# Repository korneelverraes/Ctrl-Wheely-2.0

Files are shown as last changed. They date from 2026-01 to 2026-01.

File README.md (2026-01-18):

# Ctrl-Wheely
*An innovative interface that elevates safety in modern vehicles to a higher level.* 

*Projectteam: Korneel Verraes; Warre Robbe; Seppe Nijs; Bram Tops*

19/01/2026

## Introduction
In contemporary cars, large touchscreens force drivers to take their eyes off the road, even for simple actions. This conflicts with the need for focus and safety while driving. Ctrl-Wheely originates from this tension and rethinks vehicle control more naturally. The system combines a modular rotary controller with targeted haptic feedback, allowing functions to feel intuitive and to be operated by touch rather than sight.

Essential information such as climate and media settings is displayed on a head-up display directly within the driver’s field of view. Through a carefully considered mechanical design, Ctrl-Wheely creates a robust physical interaction that feels faster, causes less distraction, and restores balance to the driving experience.

<div style="display:flex; gap:20px;">
  Wide angle view
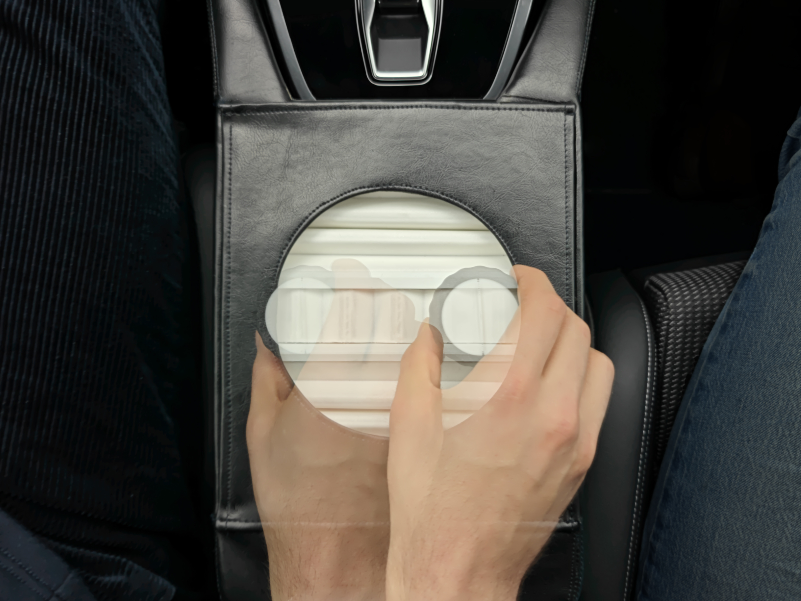
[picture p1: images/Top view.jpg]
Top view
  
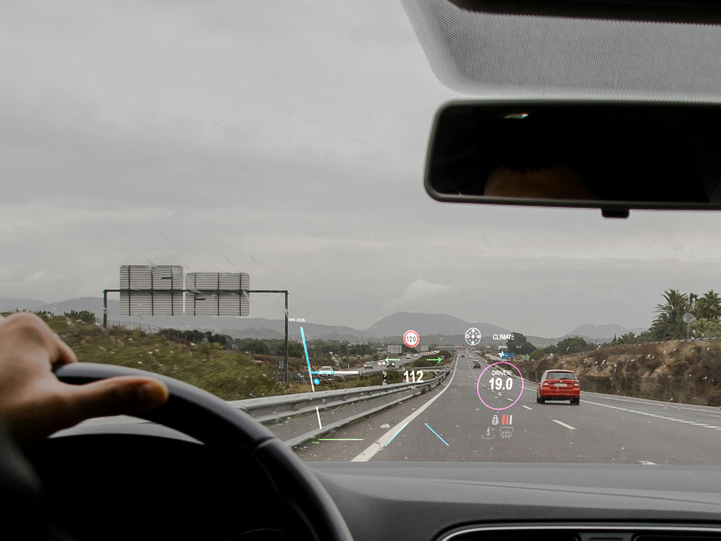
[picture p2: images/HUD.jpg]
HUD
  
</div>

## Embodiment

The product architecture consists of two main assemblies. All design files are located in the `CAD-Files` folder. Use `ASSY_V6.prt` or `ASSY_V6.stp` for the full assembly of the entire system, while `ASSY V5.prt` contains the standalone dial assembly.

**The dial** serves as a smart rotary knob inspired by [Scott Bezz's SmartKnob project](https://github.com/scottbez1/smartknob). Its primary functions include rotation with programmable haptic feedback, a central short or long press, and dedicated left and right clicking actions. The design is focused on ergonomic and intuitive use.

**The gantry system** is inspired by 3D printer mechanics and utilizes a central hub on which the dial is mounted, supported by two axes. This allows the controller to move physically within the console to navigate different menus or settings. To protect the internal mechanism from dust or debris, a dual cover system has been implemented. These covers must be printed in TPU (the softer the better for flexibility), while all other structural parts can be printed in PETG or ASA for better heat resistance in automotive environments.

<div style="display:flex; gap:20px;">
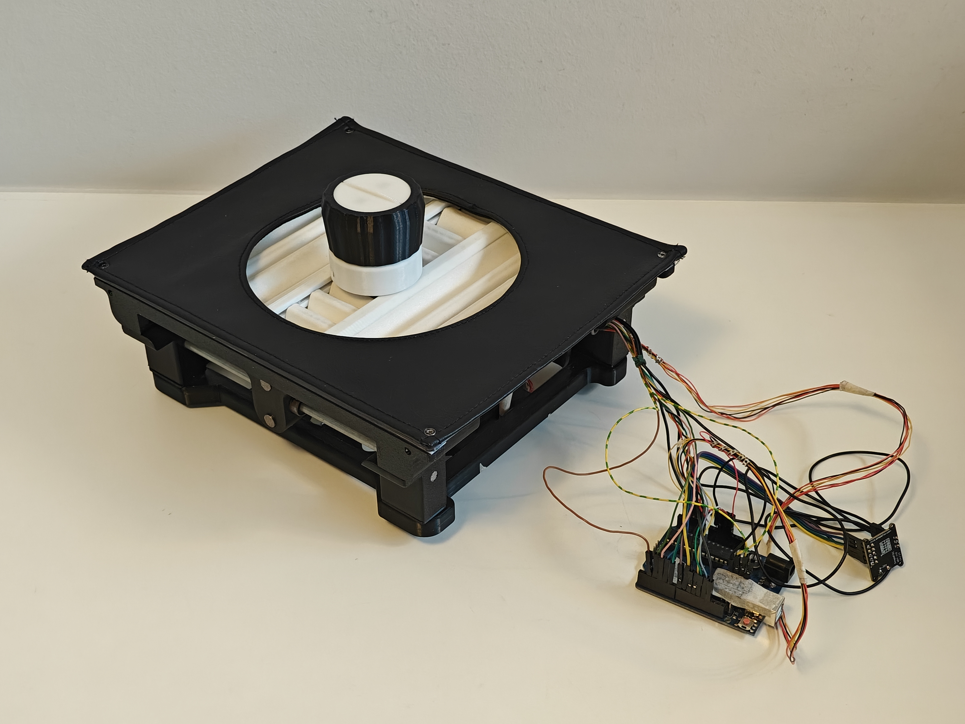
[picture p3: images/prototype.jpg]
Prototype
  
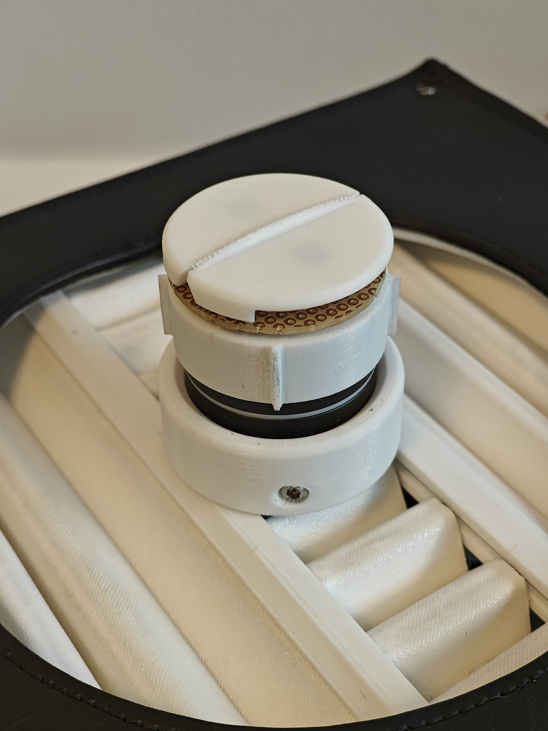
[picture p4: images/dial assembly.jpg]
Dial assembly
  
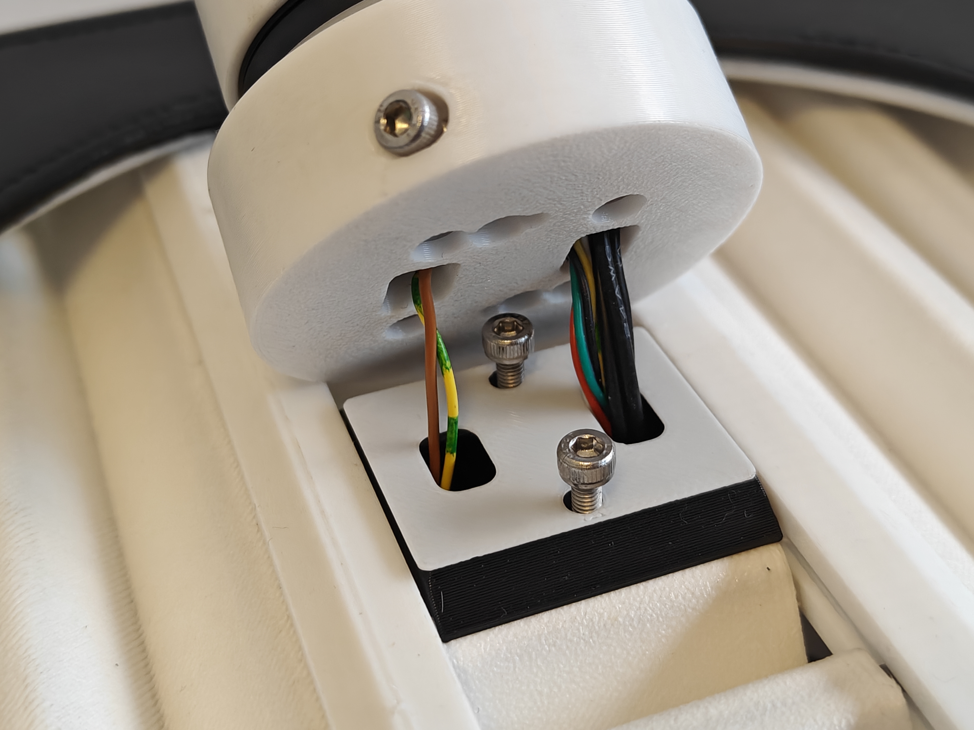
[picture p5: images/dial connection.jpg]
Dial connection
  
</div>

### Bill of Materials (BOM)
#### Mechanical components:
- 2 x Smooth steel rod (Ø6 x 217.5mm)
- 2 x Smooth steel rod (Ø8 x 190mm)
- 2 x LM8UU linear ball bearing
- 2 x LM6UU linear ball bearing
- 5 x Connecting screws & sleeves (for snapping positions)
- 1 x Neodymium magnet (Ø6 x 16mm)
- 6 x Threaded rod (Ø3 x 205mm)
- 4 x Threaded rod (Ø1 x 205mm)

#### Fasteners (dial):
- 2 x M3 x 8
- 4 x M2.5 x 16
- 4 x M2.5 x 6
- 4 x M2.5 x 10 (included in the motor kit)

#### Fasteners (gantry):
- 4 x M3 x 16
- 2 x M3 x 8
- 4 x M3 x 10
- 4 x M2 x 6

The prototype has been specifically engineered to fit the interior geometry of an **Audi Q4 e-tron**.

## Hardware

The system uses an Arduino Uno to bridge the gap between physical movement and digital feedback. All components are wired according to the electrical scheme and physical setup shown below.

### Components

- 1 x Arduino Uno  
- 1 x iPower GM3506 Gimbal Motor with Encoder  
- 1 x SimpleFOC Mini motor driver  
- 5 x DRV5053 Analog-Bipolar Hall Effect Sensors  
- 2 x Small push button (6 mm)  
- 1 x Large push button (12 mm)  
- 1 x DC power supply (8-30 V)  
- 1 x Circular prototyping board (diameter 43 mm)  

### Electrical Diagram and Hardware Setup

<div style="display:flex; gap:20px;">
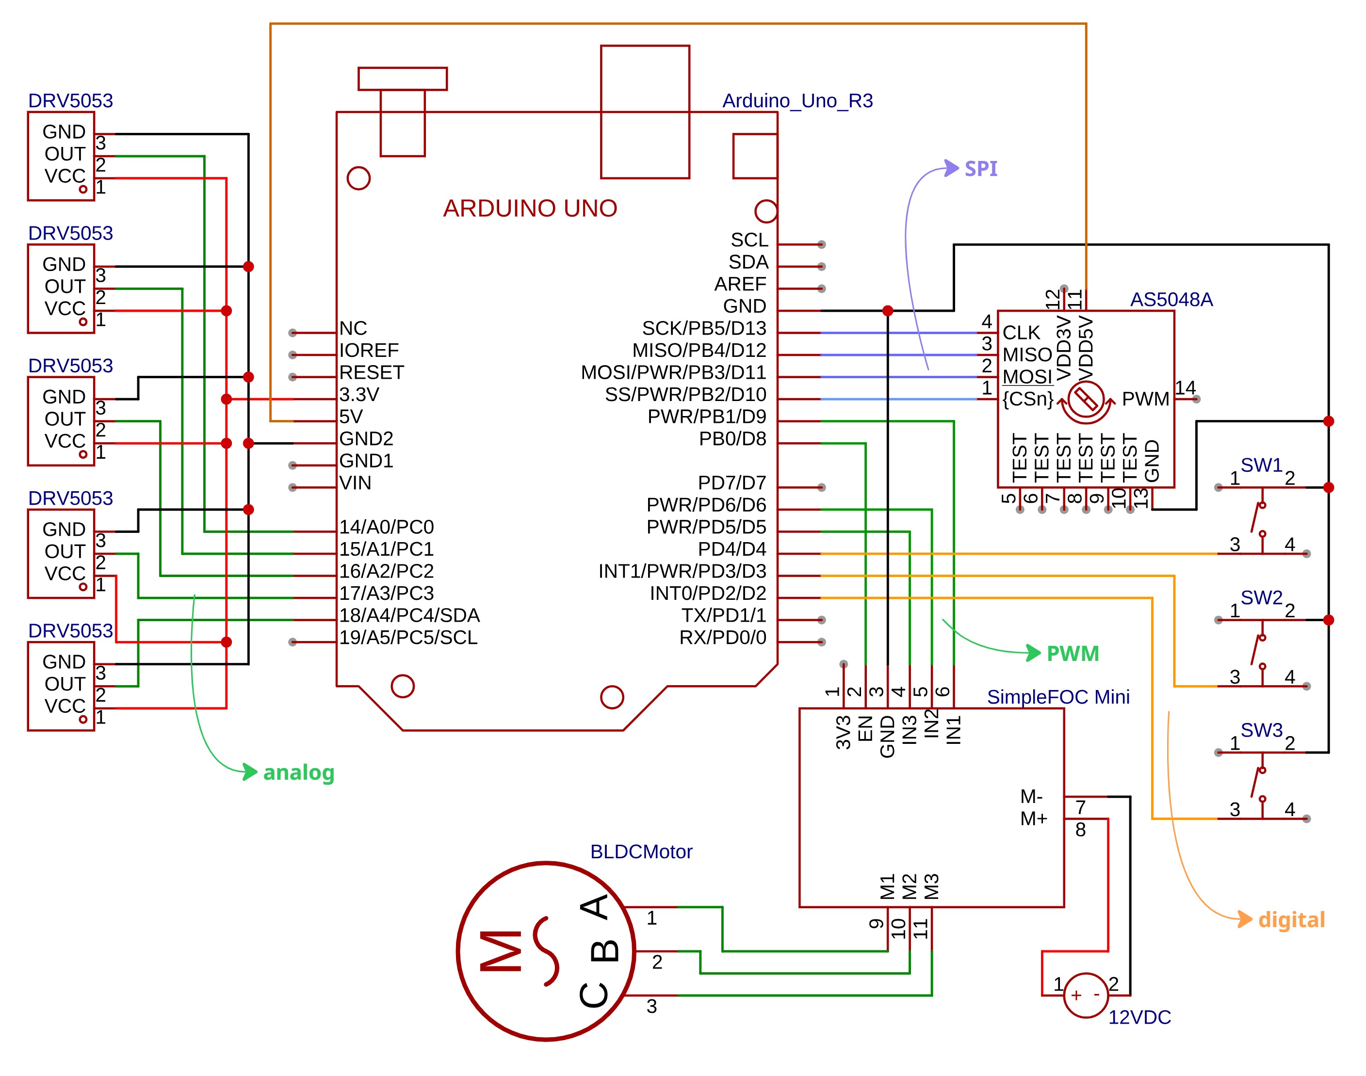
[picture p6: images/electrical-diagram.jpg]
Electrical Diagram
  
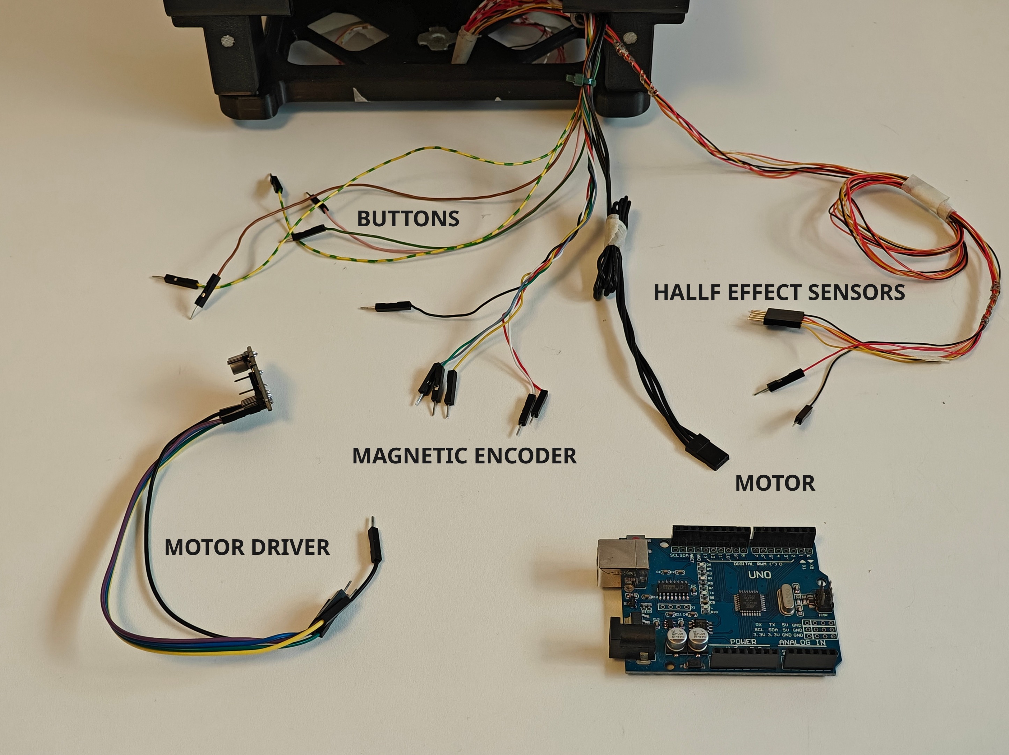
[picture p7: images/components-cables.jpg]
Hardware Setup Photo
  
</div>

| **Component** | **Connection** |
|---|---|
| **Motor driver** | **Arduino UNO** |
| EN (purple) | D8 |
| IN3 (blue) | D5 |
| IN2 (green) | D6 |
| IN1 (yellow) | D9 |
| GND (black) | GND |
| | |
| **Magnetic encoder** | **Arduino UNO** |
| GND (white) | GND |
| VDD (red) | +5V |
| MISO (green) | D12 |
| MOSI (yellow) | D11 |
| SCL (purple) | D13 |
| CS (black) | D10 |
| | |
| **Hall effect sensors** | **Arduino UNO** |
| VCC | +3.3V |
| GND | GND |
| OUT x 5 | A0 - A4 |
| | |
| **Push button (press)** | **Arduino UNO** |
| OUT (brown) | D2 |
| GND (yellow-green) | GND |
| | |
| **Push button (left / right)** | **Arduino UNO** |
| OUT left (green) | D3 |
| OUT right (pink) | D4 |
| GND (yellow-green) | GND |
| | |
| **Motor phase cables** | **Motor driver** |
| A (black) | M1 |
| B (black) | M2 |
| C (black) | M3 |

## Software
### Arduino

The Arduino serves as the core controller, managing all hardware interactions and real-time feedback loops. The complete implementation, found in `Ctrl-Wheely.ino`, leverages the [SimpleFOC library](https://simplefoc.com/) to drive the gimbal motor. This allows for high-precision haptic feedback that changes dynamically based on the active function and user input.

Before running the main Arduino code, the correct physical positions of the hall effect sensors must be determined. This is done using the calibration sketch `Magnet_pos_test.ino`. This sketch allows you to read and verify the sensor outputs while moving the magnet position.

The motor driver voltage must be set according to the external power supply used in the setup. Make sure to update the voltage value in the Arduino code to match your power supply.

```cpp
driver.voltage_power_supply = 11,2;
```

### PyGame
The project includes a Head-Up Display (HUD) that projects information onto the windshield, indicating which function is currently being controlled via the dial. In a previous iteration of the project, the HUD was developed using ProtoPie and connected to an Arduino. Due to the limitations of ProtoPie, all scenes are now fully implemented in Python using the PyGame library.

The user interface that was designed and tested within the course User-Centered Design has been recreated almost one-to-one in PyGame. This approach ensures that the validated and positively received UX is preserved in the final implementation. The system is not a simulated “Wizard of Oz” interface, but a fully functional and directly responsive HUD that accurately reflects the user’s interactions with the dial.

Within PyGame, it is possible to receive serial data directly from the Arduino, to which the dial is connected. This incoming serial input is used to dynamically update elements of the HUD in real time. The PyGame implementation was further extended with additional functionalities, including: Extra buttons, Submenus, Variable values per passenger or driver and Additional configurable interface elements

The full PyGame implementation of the HUD can be found in `UI_HUD_pygame.py`. 

Make sure to set the correct COM port on **line 55**.

```py
ser = serial.Serial('COM5', 115200, timeout=0)
```

For HUD usage, uncomment **lines 1027 and 1028** to mirror the screen over the x-axis. In this project Superdesk was used to project the HUD on a phone or tablet for projecting the HUD in the window of a car.

```py
#canvas = pygame.transform.flip(screen, False, True)
#screen.blit(canvas, (0,0))
```

<div style="display:flex; gap:20px;">
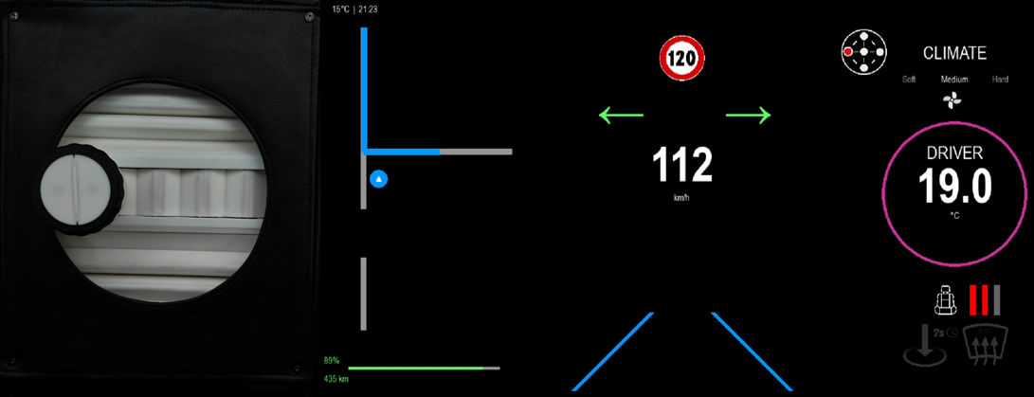
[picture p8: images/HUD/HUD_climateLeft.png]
Climate Left
  
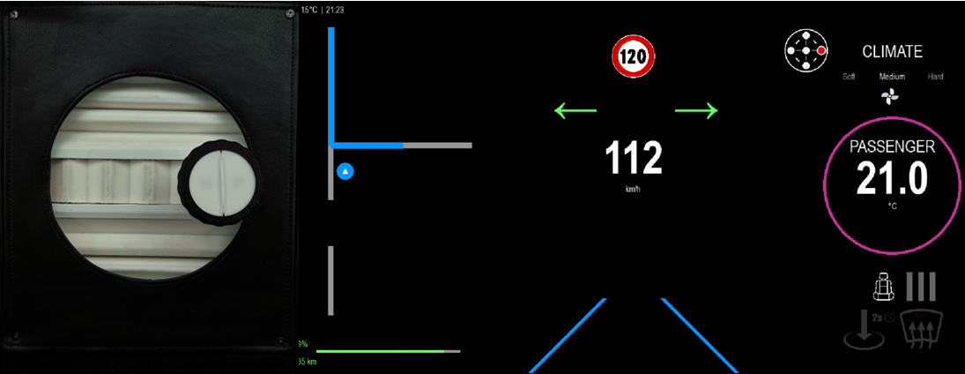
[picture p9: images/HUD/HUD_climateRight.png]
climate Right
  
</div>

<div style="display:flex; gap:20px;">
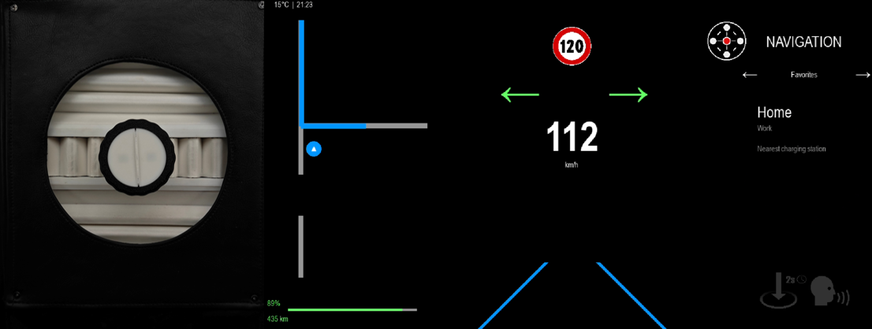
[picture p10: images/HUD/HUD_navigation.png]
  
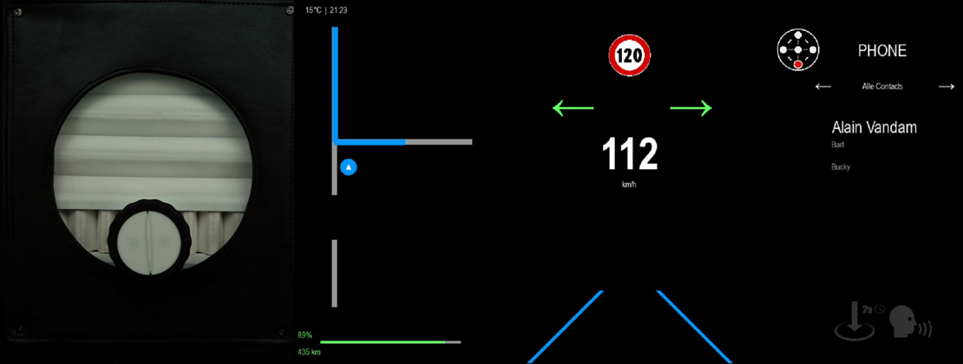
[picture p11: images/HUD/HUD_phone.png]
  
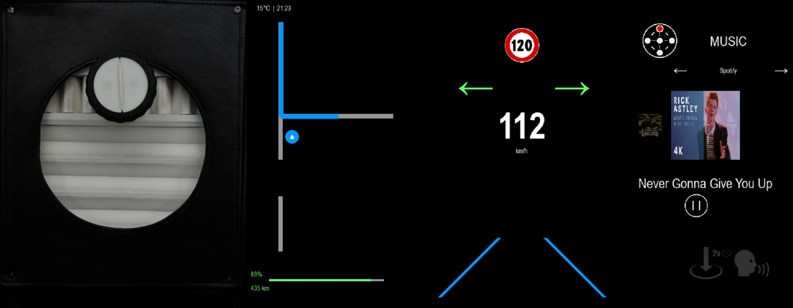
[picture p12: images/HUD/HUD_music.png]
  
</div>

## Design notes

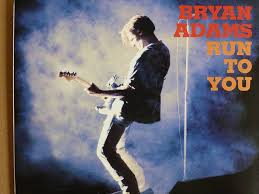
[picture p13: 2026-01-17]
software/album_d.jpg

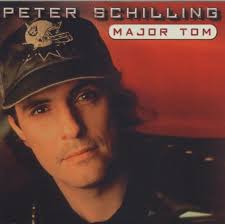
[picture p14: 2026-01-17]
software/album_e.jpg

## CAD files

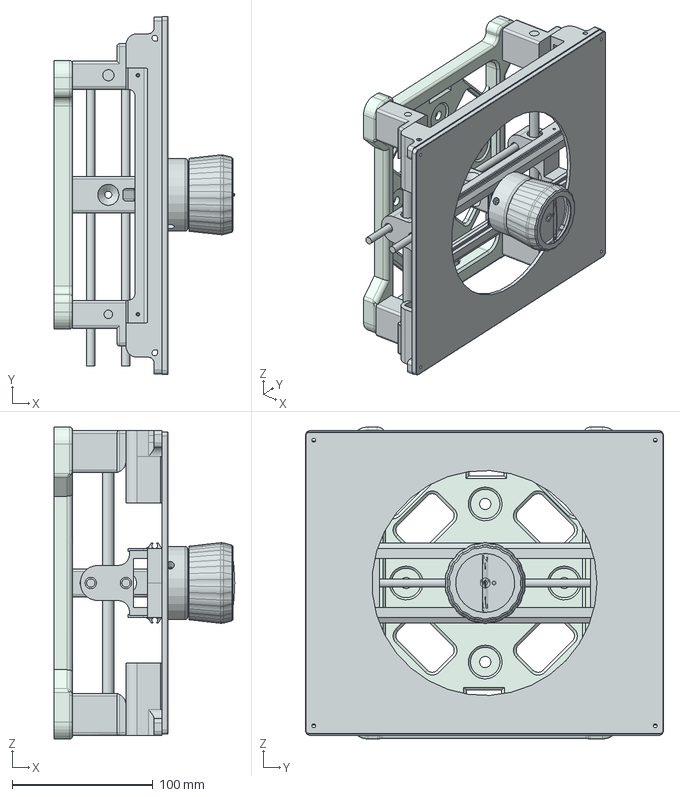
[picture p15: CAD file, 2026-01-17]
CAD files/ASSY_V6.stp
128.4 x 254.8 x 221.8 mm
rod short V5 x 2
MID rail V5 x 2
MID cross block V5 x 2
outer rail V5 x 2
rod long V5 x 2
corner piece V5 x 3
knob V5
buttonplate V5
knob spacer V5
base plate V5
clips V5
button PCB V5
button base V5
ring V5
top plate V5
MID central block V5
MID central block cover V5
bottom plate V5

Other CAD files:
CAD files/ASSY V5.prt
CAD files/ASSY_V6.prt
CAD files/MID central block V5.prt
CAD files/MID central block cover V5.prt
CAD files/MID cross block V5.prt
CAD files/MID rail V5.prt
CAD files/base plate V5.prt
CAD files/bottom plate V5.prt
CAD files/button PCB V5.prt
CAD files/button base V5.prt
CAD files/buttonplate V5.prt
CAD files/clips V5.prt
CAD files/corner piece V5.prt
CAD files/knob V5.prt
CAD files/knob spacer V5.prt
CAD files/outer rail V5.prt
CAD files/ring V5.prt
CAD files/rod long V5.prt
CAD files/rod short V5.prt
CAD files/top plate V5.prt
CAD files/tpu cover v2.prt
CAD files/tpu coverbig v2.prt

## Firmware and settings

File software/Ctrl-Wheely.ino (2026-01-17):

#include <SimpleFOC.h>

int steps[] = { 10, 8, 8, 8, 15 };
float strengths[] = { 5, 3, 3, 3, 8 };

String functions[] = { "nav", "tempL", "tempR", "music", "phone" };
String buttons[] = { "press", "left", "right" };
String RPIdata = "";

int sensorPin[] = { A0, A1, A2, A3, A4 };
int sensorValue = 0;
int buttonPin[] = { 2, 3, 4 };
int buttonState[] = { 0, 0, 0 };
int buttonLastState[] = { -1, -1, -1 };

int position = 0;
int lastPosition = 5;
bool home = false;       //voor timer
bool longPress = false;  //voor timer
int currentStep = 20;
bool limitccw = false;
bool limitcw = false;
bool spotify = false;
bool turnSent = false;

unsigned long t0 = 0;  //time-out timer
unsigned long t1 = 0;
unsigned long t2 = 0;  //longpress

float attractAngle = 0;
float lastAngle = 0;
float offsetAngle = 0;
//float localAngle = 0;
//float torqueVoltage = 0;

MagneticSensorSPI sensor = MagneticSensorSPI(10, 14, 0x3FFF);
BLDCDriver3PWM driver = BLDCDriver3PWM(9, 5, 6, 8);
BLDCMotor motor = BLDCMotor(11);
PIDController P_haptic{ .P = 5, .I = 0, .D = 0, .output_ramp = 100000, .limit = 5 };

void setup() {
  Serial.begin(115200);

  sensor.init();

  driver.pwm_frequency = 20000;
  driver.voltage_power_supply = 11,2;
  driver.voltage_limit = 5;
  driver.init();

  motor.linkSensor(&sensor);
  motor.linkDriver(&driver);
  motor.controller = MotionControlType::torque;
  motor.init();
  motor.initFOC();

  for (int i = 0; i < 3; i++) {
    pinMode(buttonPin[i], INPUT_PULLUP);
  }
}

void loop() {
  motor.loopFOC();

  t1 = _micros();

  //POSITION
  for (int i = 0; i < 5; i++) {
    sensorValue = analogRead(sensorPin[i]);
    if (sensorValue > 350) {
      position = i;
      currentStep = steps[i];
    }
    /*Serial.print(sensorValue);
    Serial.print(" | ");*/
  }
  if (home == false && t1 - t0 >= 8000000) {  //8s home timer
    home = true;
    Serial.println("home");
  }
  if (position != lastPosition) {
    Serial.println(functions[position]);
    offsetAngle = motor.shaft_angle - round(motor.shaft_angle / (2 * _PI / currentStep)) * (2 * _PI / currentStep);
    //P_haptic.P = strengths[position];
    lastAngle = attractAngle;  //elimineert minimale verdraaiing tijdens verschuiven
    limitccw = false;
    limitcw = false;
    spotify = false;
    t0 = t1;
    home = false;
    lastPosition = position;
  }

  //TURNING
  if (attractAngle > lastAngle + 0.05) { //links draaien
    if (home == true) Serial.println(functions[position]);
    Serial.println("ccw");
    limitcw = false;
    t0 = t1;
    home = false;
    lastAngle = attractAngle;
  } else if (attractAngle < lastAngle - 0.05) { //rechts draaien
    if (home == true) Serial.println(functions[position]);
    Serial.println("cw");
    limitccw = false;
    t0 = t1;
    home = false;
    lastAngle = attractAngle;
  }

  if (spotify) {  //magnetisch midden voor vorig/volgend nummer
    if (turnSent == false && motor.shaft_angle - attractAngle > 0.8) {
      if (home == true) Serial.println(functions[position]);
      Serial.println("ccw");
      limitcw = false;
      t0 = t1;
      home = false;
      turnSent = true;
    } else if (turnSent == false && attractAngle - motor.shaft_angle > 0.8) {
      if (home == true) Serial.println(functions[position]);
      Serial.println("cw");
      limitcw = false;
      t0 = t1;
      home = false;
      turnSent = true;
    } else if (abs(motor.shaft_angle - attractAngle) < 0.2) {
      turnSent = false;
    }
  }

  //CLICKING
  for (int i = 0; i < 3; i++) {
    buttonState[i] = digitalRead(buttonPin[i]);
    if (buttonState[i] == 0 && buttonLastState[i] == 1) {
      if (home == true) Serial.println(functions[position]);
      t2 = t1;
      t0 = t1;
    }
    if (i == 0 && buttonState[i] == 0) {
      if (t1 - t2 >= 1500000) {  //+/- 2s long press
        Serial.println("longpress");
        longPress = true;
        t2 = t1;
        t0 = t1;
        home = false;
      }
    }
    if (buttonState[i] == 1 && buttonLastState[i] == 0) {
      if (longPress == false) {
        Serial.println(buttons[i]);
        limitccw = false;
        limitcw = false;
        spotify = false;
        t0 = t1;
        home = false;
      } else {
        longPress = false;
      }
    }
    buttonLastState[i] = buttonState[i];
  }
  //Serial.println();

  //MOTOR
  float target = findAttractor(motor.shaft_angle);

  if (Serial.available() > 0) {
    RPIdata = Serial.readStringUntil('\n');
    RPIdata.trim();
    if (RPIdata == "limietccw") limitccw = true;
    if (RPIdata == "limietcw") limitcw = true;
    if (RPIdata == "spotify") spotify = true;
  }

  if (limitccw && target > lastAngle) { //limieten instellen
    attractAngle = lastAngle;
  } else if (limitcw && target < lastAngle) {
    attractAngle = lastAngle;
  } else if (spotify) {
    attractAngle = lastAngle;
  } else {
    attractAngle = target;
  }

  P_haptic.P = map(abs(sensor.getVelocity()), 0, 15, strengths[position], 1); //kracht van de tikjes verminderen wanneer je sneller draait
  motor.move(P_haptic(attractAngle - motor.shaft_angle));

  //Serial.println(sensor.getVelocity());
  //Serial.println(attractAngle);
  //Serial.println(P_haptic(attractAngle - motor.shaft_angle));

  /*localAngle = fmod(motor.shaft_angle, 2 * _PI / currentStep);
  if (localAngle < 0) localAngle += 2 * _PI / currentStep;
  torqueVoltage = (_PI / currentStep - localAngle) / (_PI / currentStep) * driver.voltage_limit;

  motor.move(torqueVoltage);

  Serial.print(localAngle);
  Serial.print("\t");
  Serial.print(torqueVoltage);
  Serial.print("\t");
  Serial.println(steps);*/

  //delay(100); //button debounce
}

float findAttractor(float currentAngle) {
  return round((currentAngle - offsetAngle) / (2 * _PI / currentStep)) * (2 * _PI / currentStep) + offsetAngle;
}

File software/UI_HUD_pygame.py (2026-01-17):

#libraries
import pygame
import sys
import math
import serial


#Initialisation
pygame.init()

# Screen sizes
SCREEN_WIDTH = 1200
SCREEN_HEIGHT = 650
TITLE = "HUD Ctrl-Wheely"

# Colors
DONKER_GRIJS = (0, 0, 0) # Basic HUD color
WIT = (255, 255, 255)
WIT_LICHT = (150, 150, 150)
ROOD = (255, 0, 0)
BLAUW = (0, 150, 255)
MAGENTA = (200, 50, 150)
GROEN_LICHT = (100, 255, 100)
GRIJS_LICHT = (150, 150, 150)

# create screen
screen = pygame.display.set_mode((SCREEN_WIDTH, SCREEN_HEIGHT), pygame.FULLSCREEN | pygame.SCALED)
pygame.display.set_caption(TITLE)

# Lettertypes
font_groot = pygame.font.SysFont('Arial', 80, bold=True)
font_medium = pygame.font.SysFont('Arial', 30)
font_klein = pygame.font.SysFont('Arial', 15)
font_kleinmed = pygame.font.SysFont('Arial', 22)

clock = pygame.time.Clock()

#Simulation data variables (eventually changeable at a later state with serial data)
DATA = {
    'snelheid': 112,
    'temperatuurR': 20.0,
    'temperatuurL': 20.0,
    'accu_percentage': 89,
    'bereik_km': 435,
    'max_snelheid': 120
}

active_status = ""
active_driver = ""
balk_statusL = 0
balk_statusR = 0

#Serial port Arduino
try:
    ser = serial.Serial('COM7', 115200, timeout=0)
except:
    ser = None
    print("Arduino niet gevonden")

#load images
try:
    nav = pygame.image.load('pos.nav.png').convert_alpha()
    nav = pygame.transform.scale(nav, (75, 75))
except pygame.error:
    nav = pygame.Surface((75, 75), pygame.SRCALPHA)
    nav.fill((0, 0, 255, 180))
    
try:
    phone = pygame.image.load('pos.phone.png').convert_alpha()
    phone = pygame.transform.scale(phone, (75, 75))
except pygame.error:
    phone = pygame.Surface((75, 75), pygame.SRCALPHA)
    phone.fill((255, 0, 255, 180))

try:
    tempr = pygame.image.load('pos.tempR.png').convert_alpha()
    tempr = pygame.transform.scale(tempr, (75, 75))
except pygame.error:
    tempr = pygame.Surface((75, 75), pygame.SRCALPHA)
    tempr.fill((255, 0, 255, 180))

try:
    templ = pygame.image.load('pos.tempL.png').convert_alpha()
    templ = pygame.transform.scale(templ, (75, 75))
except pygame.error:
    templ = pygame.Surface((75, 75), pygame.SRCALPHA)
    templ.fill((255, 0, 255, 180))

try:
    music = pygame.image.load('pos.music.png').convert_alpha()
    music = pygame.transform.scale(music, (75, 75))
except pygame.error:
    music = pygame.Surface((75, 75), pygame.SRCALPHA)
    music.fill((255, 0, 255, 180))
    
try:
    micro = pygame.image.load('micro.png').convert_alpha()
    micro = pygame.transform.scale(micro, (75, 75))
except pygame.error:
    micro = pygame.Surface((75, 75), pygame.SRCALPHA)
    micro.fill((0, 200, 0, 180))
try:
    stoel = pygame.image.load('carseat.png').convert_alpha()
    stoel = pygame.transform.scale(stoel, (50,50))
except pygame.error as e:
    print(f"Kon carseat.png niet laden: {e}")
    stoel = None

#Vierkant is used to draw a rectangle above a menu to draw a new menu over it by changing menus
vierkant = pygame.Rect(900, 130, 300, 800)

#Content lists for different menus
nav_favo = [
    "Home",
    "Work",
    "Nearest charging station",
    "Supermarket",
    "Gym",
    "Parents",
    "Cinema"
]

nav_recent = [
    "Hogebrugstraat 1, LO",
    "Boerderijstraat, Kortrijk",
    "Colruyt, Kortrijk",
    "Cinalco Medics, Brussel"]

nav_laadstations = [
    "Tesla Supercharger - 1 km",
    "Fastned Decathlon - 1,5 km",
    "Boost Charge - 5 km",
    "Fastned Jumbo - 9 km"]

nav_poi = [
    "Supermarkt",
    "Bakker",
    "Slager",
    "Doe-Het-Zelf",
    "Café's",
    "Ontbijt"]


phone_alle = [
    "Alain Vandam",
    "Bart",
    "Bucky",
    "Dirk",
    "Franky Loosvelt",
    "Guido Pallemans",
    "Kai",
    "Korrelneel",
    "Kwienten",
    "Liesje",
    "Michel Drets",
    "Sammy Tanghe",
    "Sippe",
    "Tessa",
    "Warre"
]

phone_favo = [
    "mama",
    "papa",
    "mokke",
    "Korrelneel",
    "Bart",
    "Sippe",
    "Warre"]

phone_recent = [
    "mokke",
    "Bucky",
    "Korrelneel",
    "Bart",
    "papa",
    "Sippe"]

music_spotify = [
    {"title": "Never Gonna Give You Up", "artist": "Rick Astley", "image": "album_a.jpg"},
    {"title": "Get Wrecked", "artist": "Dual Damage", "image": "album_b.jpg"},
    {"title": "Rhythm Nation", "artist": "Janet Jackson", "image": "album_c.jpg"},
    {"title": "Run To You", "artist": "Bryan Adams", "image": "album_d.jpg"},
    {"title": "Up Café", "artist": "Kartje Kilo", "image": "album_e.png"},
]

music_radio = [
    "Joe",
    "MNM",
    "NRJ",
    "Nostalgie",
    "Qmusic",
    "Radio 1",
    "Radio 2",
    "Studio Brussel (Stubru)",
    "Willy",
    "Zenith FM" 
]


    

phone_lijsten = {0: phone_alle,
                 1: phone_favo,
                 2: phone_recent}

nav_lijsten = {0: nav_favo,
               1: nav_recent,
               2: nav_laadstations,
               3: nav_poi}

music_lijsten = {0: music_spotify,
                 1: music_radio,
                 2: music_spotify,
                 3: music_spotify}



navi_keuze = ["Favorites",
              "Recente Bestemmingen",
              "Dichtsbijzijnde laadstations",
              "POI"]

phone_keuze = ["Alle Contacts",
               "Favorieten",
               "Recent"]

music_keuze = ["Spotify",
               "Radio",
               "Bluetooth",
               "USB"]

#Variables menu indexes, apart settings per person, ...
selected_index = 0
nav_index = 0
phone_index = 0
music_index = 0
scroll_offset = 0
current_song = 1

CENTER_SIZE = 150
SIDE_SIZE = 50
ALBUM_Y = 200

ventil = 1
ruit = 0

navig = 0

indexphone = 0

indexmusic = 0

iconmusic = 0
calling = 0
start_calling = 0
calling_timer = 0

dest = 0

micro_start_time = 0
microvalue = 0

actieve_gps = ""
actieve_phone = ""

#load music album images
def laad_muziek(data):
    geladen_afbeelding = {}
    for item in data:
        path = item['image']
        try:
            img = pygame.image.load(path).convert_alpha()
            geladen_afbeelding[path] = img
        except pygame.error:
            print(f"Kon {path} niet laden. Gebruik placeholder.")
            placeholder = pygame.Surface((CENTER_SIZE, CENTER_SIZE))
            placeholder.fill(BLAUW) 
            geladen_afbeelding[path] = placeholder

    return geladen_afbeelding

loaded_images = laad_muziek(music_spotify)
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

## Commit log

2026-01-17 Add files via upload
    CAD files meant for Siemens NX / step-files
    For a complete build, the next parts are required:
    8x M2.5x20
    8x M3x10
    4x M2x4
    4x M2x2
    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
    [ASSY V5.prt, ASSY_V6.prt, ASSY_V6.stp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]
2026-01-17 Create CAD-files
